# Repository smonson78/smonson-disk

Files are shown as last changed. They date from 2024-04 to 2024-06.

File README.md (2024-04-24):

# Smonson Disk
SD card (2x) to ACSI hard drive interface.

This project aims to develop a reliable and useful hard drive solution for Atari ST with two SD card sockets and a
battery-backed clock, satisfying the ACSI protocol, voltage, and timing requirements as given in available specifications.

Features:
- FPGA-controlled ACSI interface to ensure timing conforms to the specification
- One front-mounted removable SD card socket
- One internally-mounted microSD card socket
- SD cards running on a 10MHz SPI bus (1.25MB/s throughput)
- Battery-backed real-time clock
- GUI configuration from ST (once someone writes it...) and stored in EEPROM
- Open-source, so if you want a feature all you have to do is write it and fit it into the 110KB of code space that is currently left!

## How to build and upload:

### Building the microcontroller firmware:
#### Prerequisites
You will need to install:
- A version of GCC that includes support for `avr128da` microcontrollers, cross-compiled for AVR (e.g. 5.4.0).
- A very recent version of avr-libc that has support for `avr128da` microcontrollers - https://www.nongnu.org/avr-libc/. You may need to get this from their github repo.
- A copy of the avr128da "atpack" from Microchip - go to https://packs.download.microchip.com/ and search for `avr128da`; "
Microchip AVR-Dx Series Device Support (2.4.286)" will pop open. Download this file, then change the file extension to `.zip` 
and unzip it into the directory `mcu-source/atpack`.
- (if you are using an Arduino as a programmer) A copy of jtag2updi from the githup repo here: https://github.com/ElTangas/jtag2updi. You will already have this on your system from when you programmed the device.

#### Building
1. Inside `mcu-source`:
1. Update the `Makefile` and set up `LIBC` variable to reflect the path to `avr-libc` on your system
1. Update the `AVRDUDE` variable to reflect your programmer setup (probably just the `avrdude.conf` path)
1. With the UPDI programmer connected, build the source and flash the microcontroller with `make flash`

### Building the FPGA configuration ROM image:

#### Prerequisites
You will need to install Quartus Lite which is a free download from Intel, although you will need to create an account.
Make sure you install MAX V family support
You will also need a "USB-Blaster" or compatible programmer.
If using Linux, you will very likely need to install a `udev` "rules" file for the programmer before it'll work.

#### Building
Just open the project in Quartus, go to "start compilation", then after it's compiled, open the programmer tool and program the chip. It should auto-detect the settings. If it doesn't find the USB Blaster hardware then it's probably udev's fault.

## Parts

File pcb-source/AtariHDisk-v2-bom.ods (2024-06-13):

Designator | Footprint | Quantity | Designation | Supplier and ref
C5,C8,C9 | C_1206_3216Metric | 3 | 4.7uF | 187-CL31B475KPHNNNE
C3 | CP_Radial_D5.0mm_P2.00mm | 1 | 4.7uF | 232-16ZLH100MEFC5X11
J1 | PinHeader_2x05_P2.54mm_Vertical | 1 | JTAG
R12,R11,R25,R26 | R_0805_2012Metric | 4 | 1K
R13,R3 | R_0805_2012Metric | 2 | 10K
C18,C12,C17,C16,C14,C15,C21,C19,C25,C20,C26,C24,C27,C4,C11,C28,C13 | C_0603_1608Metric | 17 | 0.1uF
H4,H3,H1,H2 | Altronics_H0190_mounting_hole | 4 | MountingHole
U7 | SOT-223-3_TabPin2 | 1 | AMS1117-3.3 | 621-AZ1117CH-3.3TRG1
U8 | SOT-223-3_TabPin2 | 1 | AMS1117-1.8 | 621-AZ1117CH-1.8TRG1
U4 | XO_7x5 | 1 | Oscillator7x5 | 729-FNETHE025
J5 | BarrelJack_Horizontal | 1 | Conn_01x02_Female | 710-694106301002
U9 | TQFP-100_14x14mm_P0.5mm | 1 | 5M80Z | 5M80ZT100C5N
U5 | MSOP-10_3x3mm_P0.5mm | 1 | MCP795xx | 579-MCP79510-I/MS
U3 | SOT-223-3_TabPin2 | 1 | AZ1117-5.0 | 621-AZ1117CH-5.0TRG1
D6,D5 | LED_D3.0mm_Horizontal_O1.27mm_Z2.0mm | 2 | LED | 78-TLUG2401 78-TLUO2401
C22,C10,C2,C7 | C_0603_1608Metric | 4 | C | 963-UMK107BJ104KA-T
J2 | PinHeader_1x02_P2.54mm_Vertical | 1 | Program_enable | 737-PH2-80-UA
R19,R20,R24,R23,R15,R2,R21,R14,R18,R17,R1,R22 | R_0805_2012Metric | 12 | 220 | 603-RC0805JR-13220RL
Q4,Q3 | SOT-23 | 2 | BC847 | 637-BC847A
U2 | TSSOP-16_4.4x5mm_P0.65mm | 1 | MAX3232 | 595-MAX3232IPWR
U6 | LQFP-48_7x7mm_P0.5mm | 1 | STM32C031CxT | 511-STM32C031C6T6
Y1 | Crystal_SMD_ECX_31B-2Pin_3.2x1.5mm | 1 | 32KHz | ECS-.327-6-34R-C-TR
J14 | MicroSD_card_MSD-4-A | 1 | MicroSD Card 0 | 179-MSD-4-A
D2,D1 | D_1206_3216Metric | 2 | D_Schottky | 581-SD1206S040S1R0
J3 | Amphenol_SD_Card_GSD090012SEU | 1 | SD Card 1 | 523-GSD090012SEU
U1 | TSSOP-20_4.4x6.5mm_P0.65mm | 1 | 74LVC245 | 595-SN74LVC245APWR
J6 | PinHeader_2x03_P2.54mm_Vertical | 1 | Conn_02x03_Odd_Even | 737-PH2-80-UA
C29,C30 | C_0603_1608Metric | 2 | 4pF | 603-CC0603BRNPO9BN4R
D3 | D_SMA | 1 | D | 241-GS1MWG_R1_00001
J7 | PinHeader_2x05_P2.54mm_Vertical | 1 | ST-LINK
U11 | TSSOP-24_4.4x7.8mm_P0.65mm | 1 | 74LVC8T245 | 771-74LVC8T245PW118
JP1 | SolderJumper-2_P1.3mm_Open_RoundedPad1.0x1.5mm | 1 | SolderJumper_2_Open
J10 | IDC-Header_DB19_P2.54mm_Horizontal | 1 | ST ACSI BUS | 737-BHR-20-HUA
BT1 | 712-BAT-HLD-002-SMT | 1 | Battery_Cell | 712-BAT-HLD-002-SMT

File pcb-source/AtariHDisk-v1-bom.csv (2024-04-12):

Id | Designator | Footprint | Quantity | Designation | Supplier and ref
1 | C5,C8,C9 | C_1206_3216Metric | 3 | 4.7uF
2 | J4 | PinHeader_2x03_P2.54mm_Vertical | 1 | UPDI
3 | C3 | CP_Radial_D5.0mm_P2.00mm | 1 | 4.7uF
4 | J1 | PinHeader_2x05_P2.54mm_Vertical | 1 | JTAG
5 | R12,R11 | R_0805_2012Metric | 2 | 1K
6 | R13,R3 | R_0805_2012Metric | 2 | 10K
7 | C18,C12,C17,C16,C14,C15,C19,C25,C6,C20,C26,C24,C27,C4,C11,C13,C1 | C_0603_1608Metric | 17 | 0.1uF
8 | H4,H3,H1,H2 | Altronics_H0190_mounting_hole | 4 | MountingHole
9 | U7 | SOT-223-3_TabPin2 | 1 | AMS1117-3.3
10 | U8 | SOT-223-3_TabPin2 | 1 | AMS1117-1.8
11 | U4 | XO_7x5 | 1 | Oscillator7x5
12 | J5 | BarrelJack_Horizontal | 1 | Conn_01x02_Female
13 | C21,C22,C10,C28,C2,C7 | C_0603_1608Metric | 6 | C
14 | U9 | TQFP-100_14x14mm_P0.5mm | 1 | 5M80Z
15 | U5 | MSOP-10_3x3mm_P0.5mm | 1 | MCP795xx
16 | U3 | SOT-223-3_TabPin2 | 1 | AZ1117-5.0
17 | D6,D5 | LED_D3.0mm_Horizontal_O1.27mm_Z2.0mm | 2 | LED
18 | J2 | PinHeader_1x02_P2.54mm_Vertical | 1 | Program_enable
19 | U6 | LQFP-48_7x7mm_P0.5mm | 1 | ~
20 | R19,R20,R24,R23,R15,R2,R21,R14,R1,R22 | R_0805_2012Metric | 10 | 220
21 | Q4,Q3 | SOT-23 | 2 | BC847
22 | U2 | TSSOP-16_4.4x5mm_P0.65mm | 1 | MAX3232
23 | Y1 | Crystal_C38-LF_D3.0mm_L8.0mm_Vertical | 1 | 32KHz
24 | J14 | MicroSD_card_MSD-4-A | 1 | MicroSD Card 0
25 | D2,D1 | D_1206_3216Metric | 2 | D_Schottky
26 | R25,R26 | R_0805_2012Metric | 2 | R
27 | J3 | Amphenol_SD_Card_GSD090012SEU | 1 | SD Card 1
28 | U1 | TSSOP-20_4.4x6.5mm_P0.65mm | 1 | 74LVC245
29 | R18,R17 | R_0805_2012Metric | 2 | 2K
30 | J6 | PinHeader_2x03_P2.54mm_Vertical | 1 | Conn_02x03_Odd_Even
31 | C29,C30 | C_0603_1608Metric | 2 | 3pF
32 | D3 | D_1206_3216Metric | 1 | D
33 | U11 | TSSOP-24_4.4x7.8mm_P0.65mm | 1 | 74LVC8T245
34 | J10 | IDC-Header_DB19_P2.54mm_Horizontal | 1 | ST ACSI BUS
35 | BT1 | 712-BAT-HLD-002-SMT | 1 | Battery_Cell

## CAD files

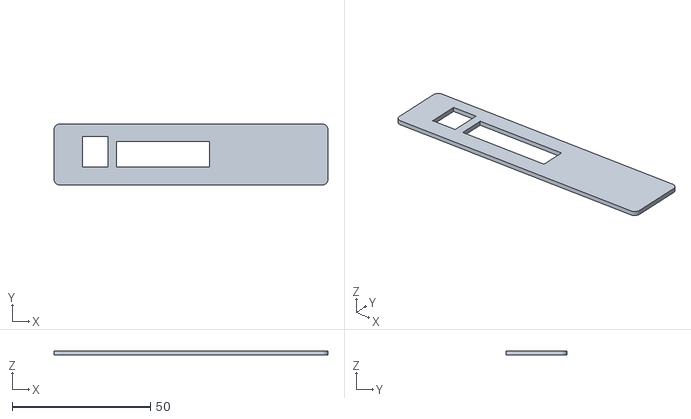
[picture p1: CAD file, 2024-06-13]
enclosure/back.stl
99.0 x 22.0 x 1.50

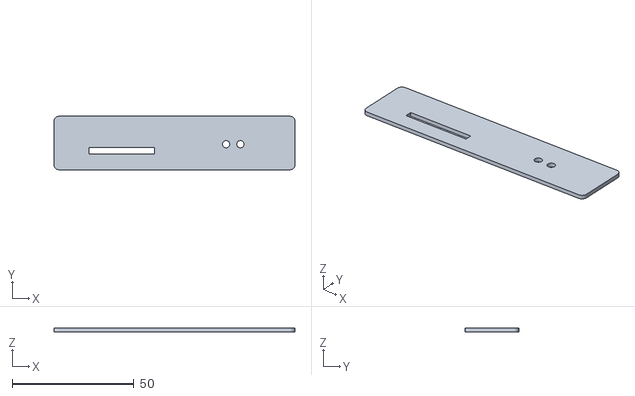
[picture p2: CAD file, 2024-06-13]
enclosure/front.stl
99.0 x 22.0 x 1.50

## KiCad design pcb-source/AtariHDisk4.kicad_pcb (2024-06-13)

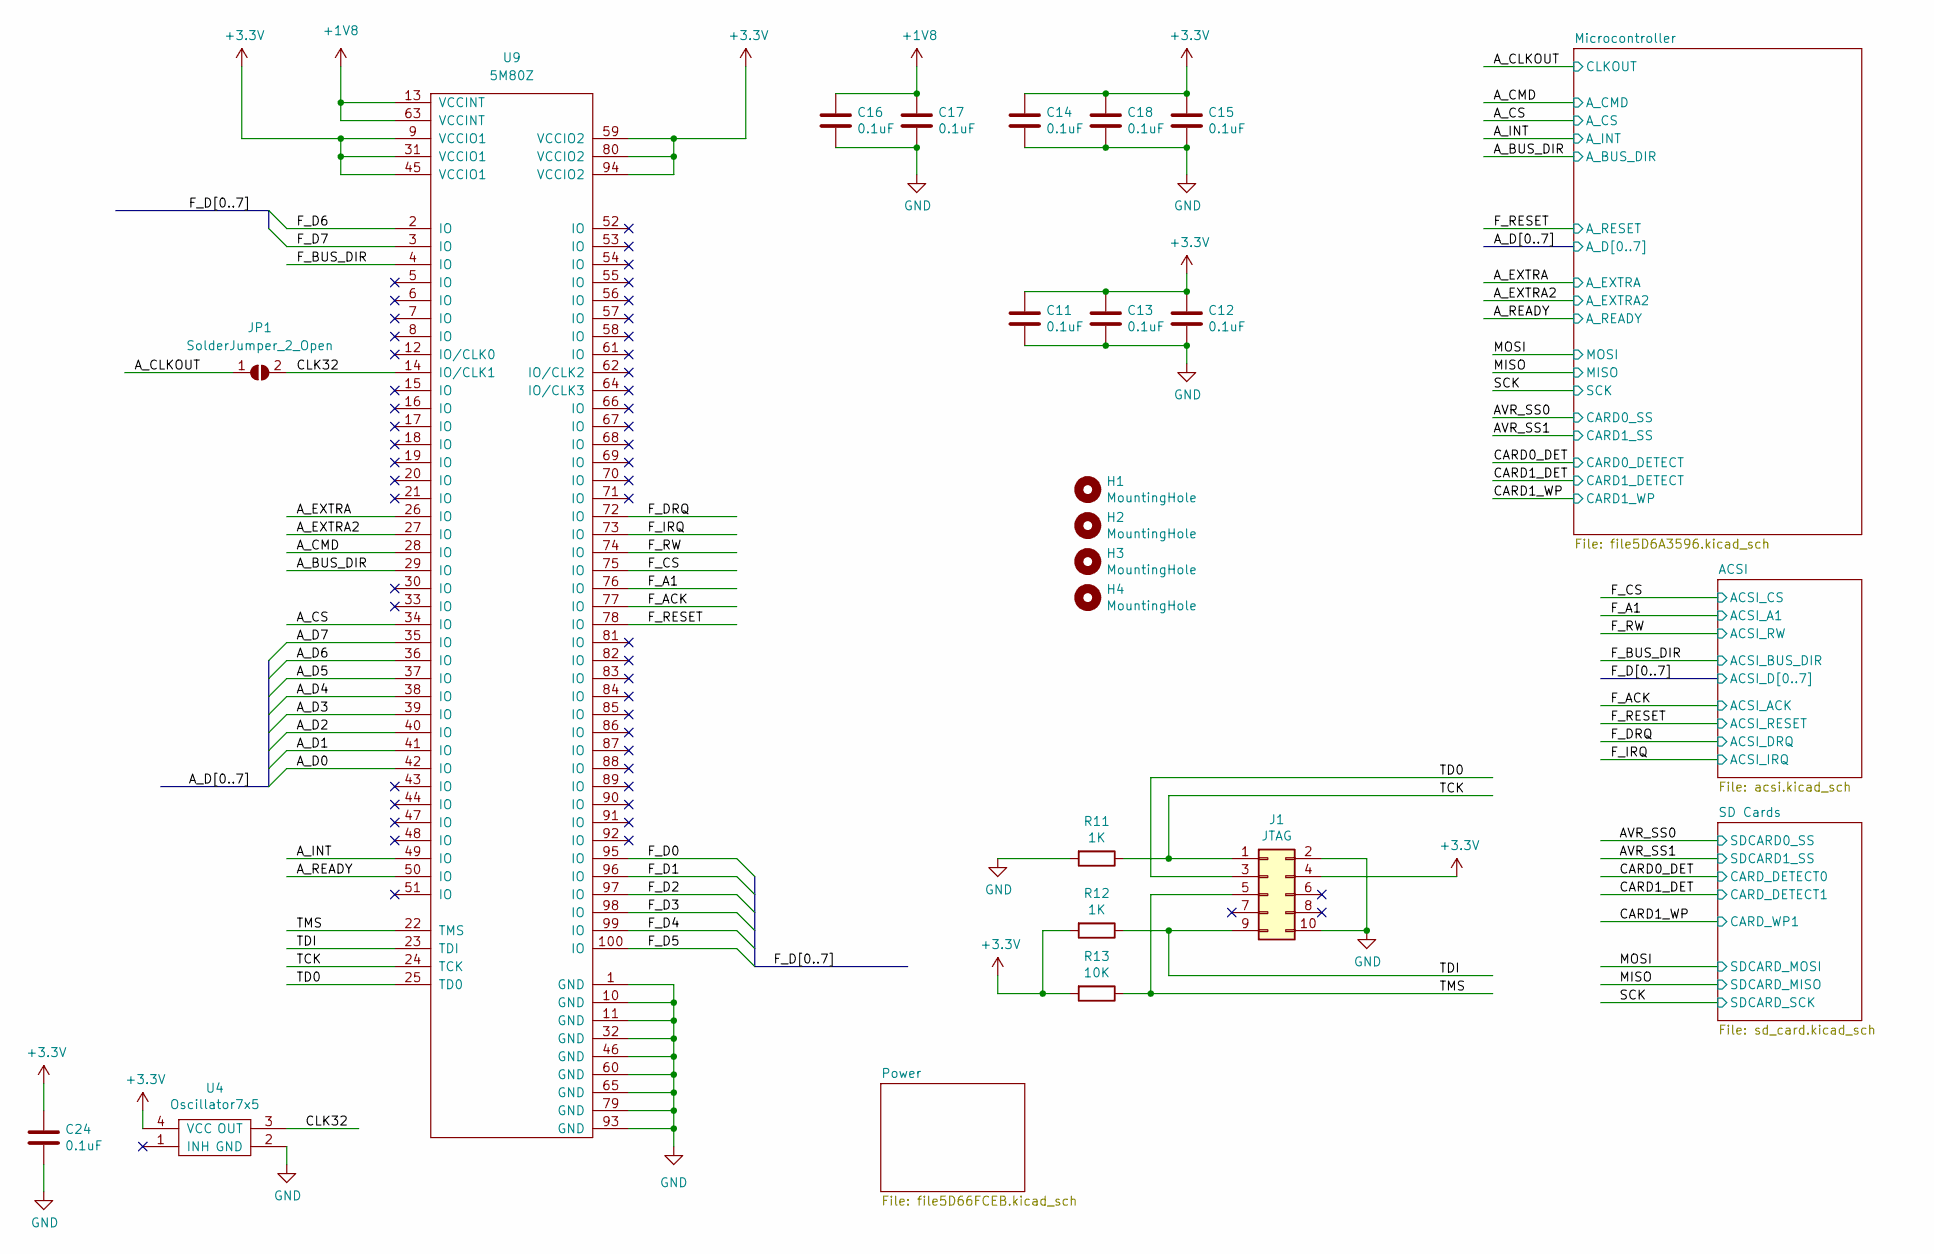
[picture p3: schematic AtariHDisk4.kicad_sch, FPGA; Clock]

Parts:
C11, C12, C13, C14, C15, C16, C17, C18, C24: 0.1uF; C_0603_1608Metric
H1, H2, H3, H4: MountingHole; Altronics_H0190_mounting_hole
J1: JTAG; PinHeader_2x05_P2.54mm_Vertical
JP1: SolderJumper_2_Open; SolderJumper-2_P1.3mm_Open_RoundedPad1.0x1.5mm
R11, R12: 1K; R_0805_2012Metric
R13: 10K; R_0805_2012Metric
U4: Oscillator7x5; XO_7x5
U9: 5M80Z; TQFP-100_14x14mm_P0.5mm

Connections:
+1V8: C16.1, C17.1, U9.13 (VCCINT), U9.63 (VCCINT); also elsewhere on the board
+3V3: C11.1, C12.1, C13.1, C14.1, C15.1, C18.1, C24.1, J1.4, R12.2, R13.2, U4.4 (VCC), U9.9 (VCCIO1), U9.31 (VCCIO1), U9.45 (VCCIO1), U9.59 (VCCIO2), U9.80 (VCCIO2), U9.94 (VCCIO2); also elsewhere on the board
/A_BUS_DIR: U9.29 (IO); also elsewhere on the board
/A_CLKOUT: JP1.1 (A); also elsewhere on the board
/A_CMD: U9.28 (IO); also elsewhere on the board
/A_CS: U9.34 (IO); also elsewhere on the board
/A_D0: U9.42 (IO); also elsewhere on the board
/A_D1: U9.41 (IO); also elsewhere on the board
/A_D2: U9.40 (IO); also elsewhere on the board
/A_D3: U9.39 (IO); also elsewhere on the board
/A_D4: U9.38 (IO); also elsewhere on the board
/A_D5: U9.37 (IO); also elsewhere on the board
/A_D6: U9.36 (IO); also elsewhere on the board
/A_D7: U9.35 (IO); also elsewhere on the board
/A_EXTRA: U9.26 (IO); also elsewhere on the board
/A_EXTRA2: U9.27 (IO); also elsewhere on the board
/A_INT: U9.49 (IO); also elsewhere on the board
/A_READY: U9.50 (IO); also elsewhere on the board
/CLK32: JP1.2 (B), U4.3 (OUT), U9.14 (IO/CLK1)
/F_A1: U9.76 (IO); also elsewhere on the board
/F_ACK: U9.77 (IO); also elsewhere on the board
/F_BUS_DIR: U9.4 (IO); also elsewhere on the board
/F_CS: U9.75 (IO); also elsewhere on the board
/F_D0: U9.95 (IO); also elsewhere on the board
/F_D1: U9.96 (IO); also elsewhere on the board
/F_D2: U9.97 (IO); also elsewhere on the board
/F_D3: U9.98 (IO); also elsewhere on the board
/F_D4: U9.99 (IO); also elsewhere on the board
/F_D5: U9.100 (IO); also elsewhere on the board
/F_D6: U9.2 (IO); also elsewhere on the board
/F_D7: U9.3 (IO); also elsewhere on the board
/F_DRQ: U9.72 (IO); also elsewhere on the board
/F_IRQ: U9.73 (IO); also elsewhere on the board
/F_RESET: U9.78 (IO); also elsewhere on the board
/F_RW: U9.74 (IO); also elsewhere on the board
/TCK: J1.1, R11.1, U9.24 (TCK)
/TD0: J1.3, U9.25 (TD0)
/TDI: J1.9, R12.1, U9.23 (TDI)
/TMS: J1.5, R13.1, U9.22 (TMS)
GND: C11.2, C12.2, C13.2, C14.2, C15.2, C16.2, C17.2, C18.2, C24.2, J1.2, J1.10, R11.2, U4.2 (GND), U9.1 (GND), U9.10 (GND), U9.11 (GND), U9.32 (GND), U9.46 (GND), U9.60 (GND), U9.65 (GND), U9.79 (GND), U9.93 (GND); also elsewhere on the board

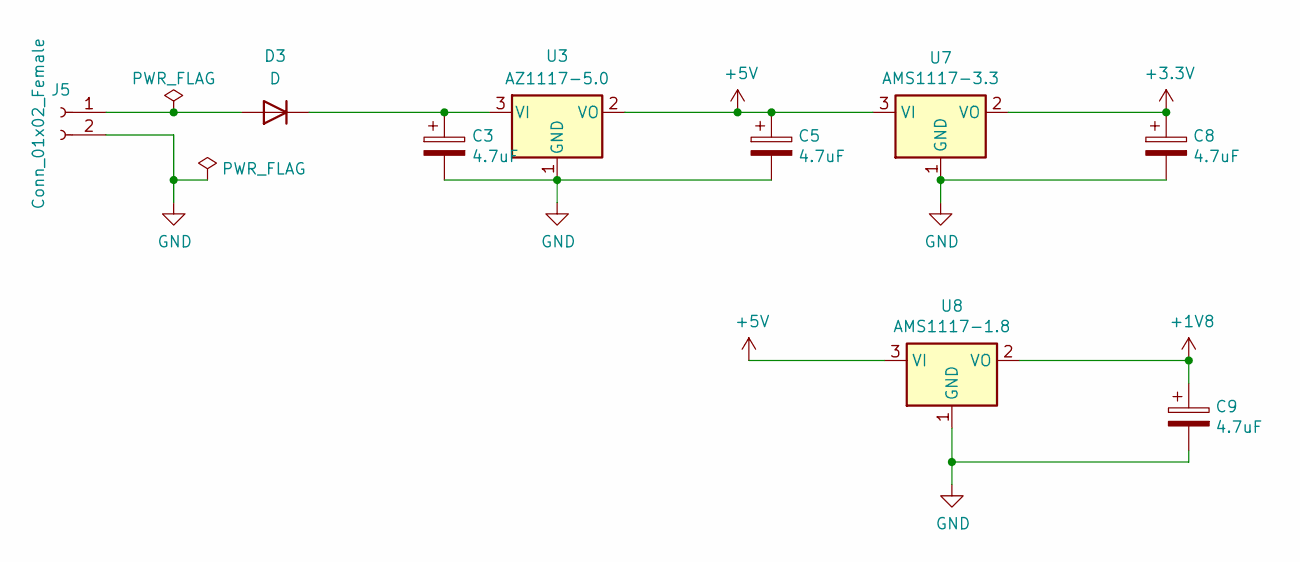
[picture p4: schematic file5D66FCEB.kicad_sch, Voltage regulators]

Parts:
C3: 4.7uF; CP_Radial_D5.0mm_P2.00mm
C5, C8, C9: 4.7uF; C_1206_3216Metric
D3: D; D_SMA
J5: Conn_01x02_Female; BarrelJack_Horizontal
U3: AZ1117-5.0; SOT-223-3_TabPin2
U7: AMS1117-3.3; SOT-223-3_TabPin2
U8: AMS1117-1.8; SOT-223-3_TabPin2

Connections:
+1V8: C9.1, U8.2 (VO); also elsewhere on the board
+3V3: C8.1, U7.2 (VO); also elsewhere on the board
+5V: C5.1, U3.2 (VO), U7.3 (VI), U8.3 (VI); also elsewhere on the board
GND: C3.2, C5.2, C8.2, C9.2, J5.2, U3.1 (GND), U7.1 (GND), U8.1 (GND); also elsewhere on the board
unnamed: D3.2 (A), J5.1
unnamed: C3.1, D3.1 (K), U3.3 (VI)

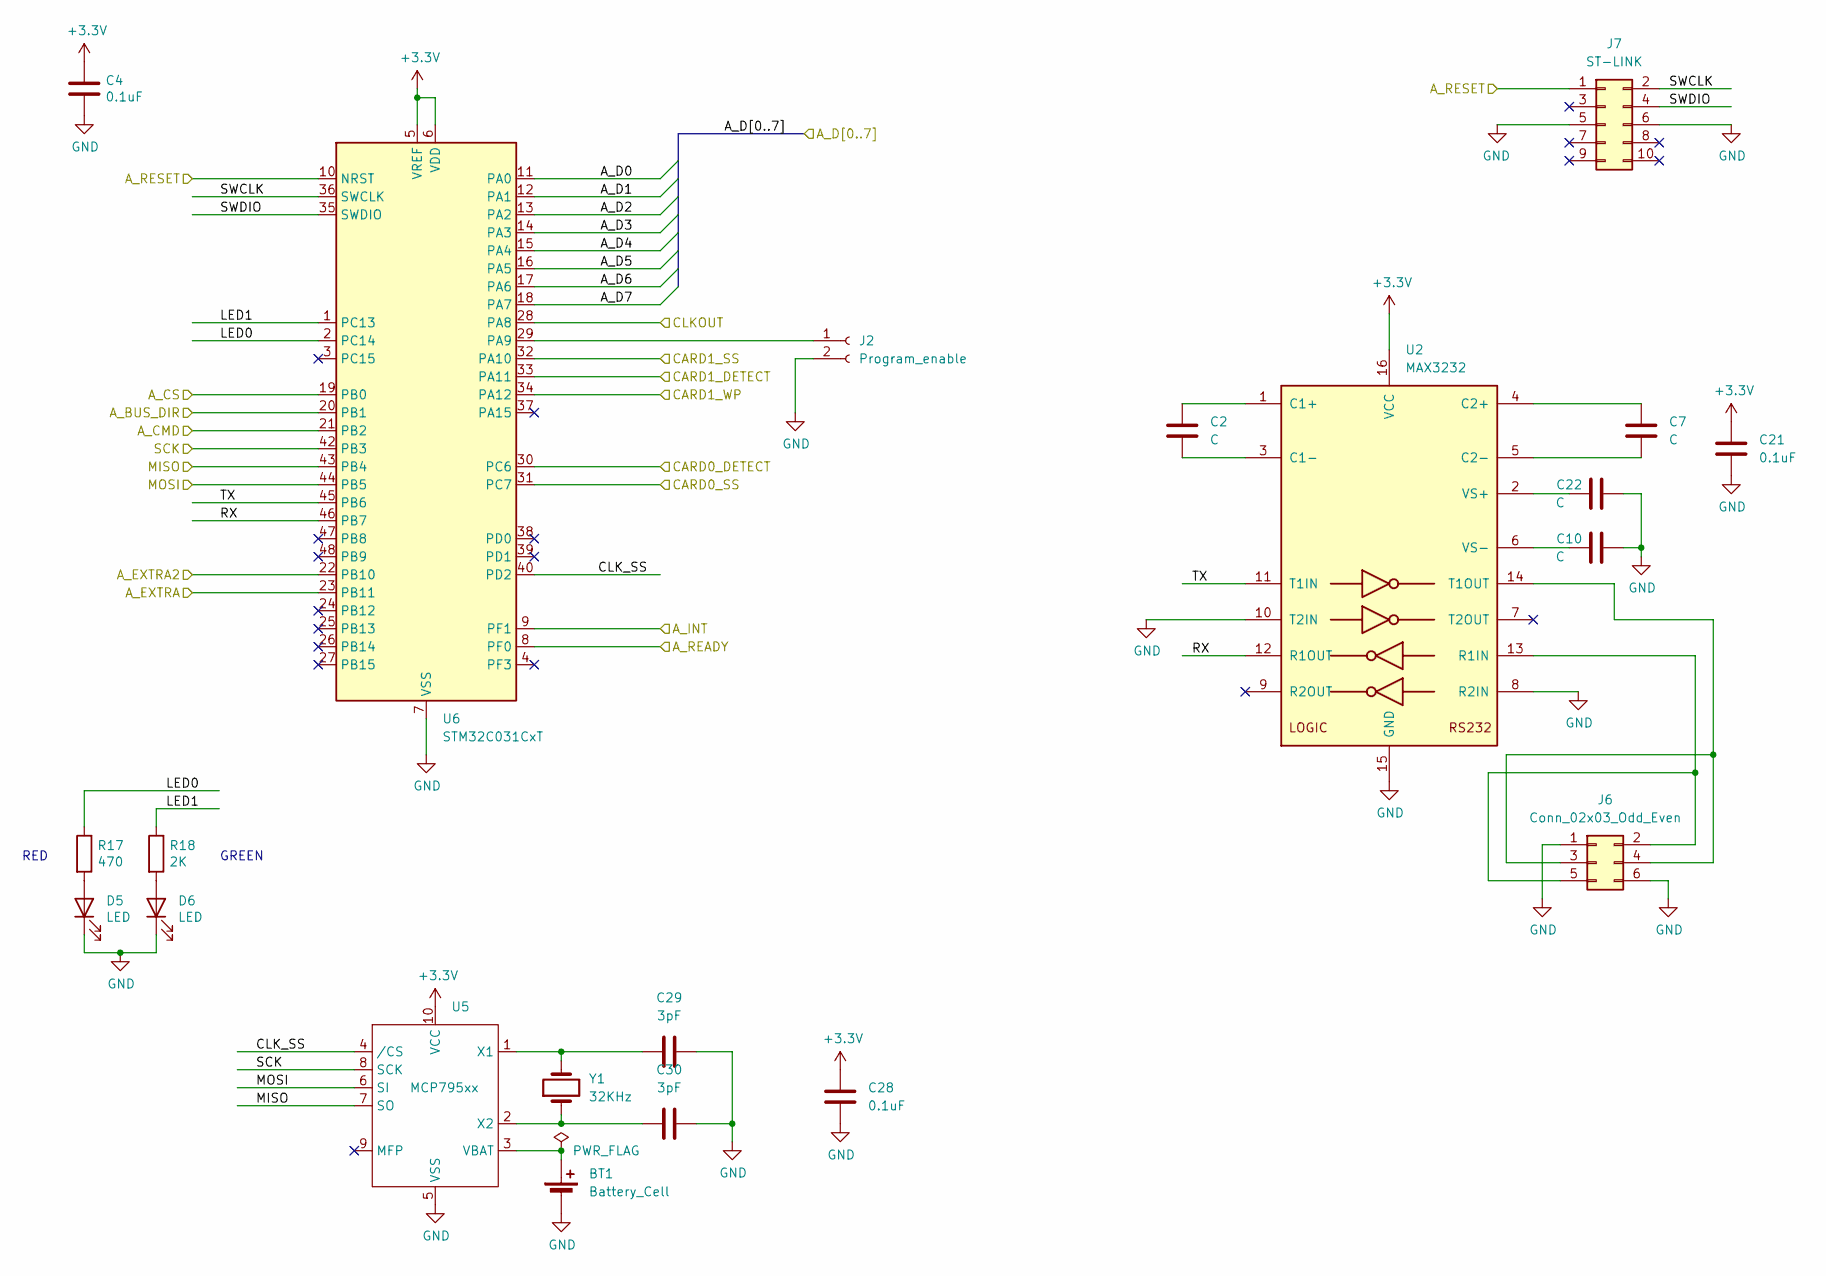
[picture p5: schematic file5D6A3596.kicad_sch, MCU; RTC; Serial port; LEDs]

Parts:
BT1: Battery_Cell; 712-BAT-HLD-002-SMT
C2, C7, C10, C22: C; C_0603_1608Metric
C4, C21, C28: 0.1uF; C_0603_1608Metric
C29, C30: 3pF; C_0603_1608Metric
D5, D6: LED; LED_D3.0mm_Horizontal_O1.27mm_Z2.0mm
J2: Program_enable; PinHeader_1x02_P2.54mm_Vertical
J6: Conn_02x03_Odd_Even; PinHeader_2x03_P2.54mm_Vertical
J7: ST-LINK; PinHeader_2x05_P2.54mm_Vertical
R17: 470; R_0805_2012Metric
R18: 2K; R_0805_2012Metric
U2: MAX3232; TSSOP-16_4.4x5mm_P0.65mm
U5: MCP795xx; MSOP-10_3x3mm_P0.5mm
U6: STM32C031CxT; LQFP-48_7x7mm_P0.5mm
Y1: 32KHz; Crystal_SMD_ECX_31B-2Pin_3.2x1.5mm

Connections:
+3V3: C4.1, C21.1, C28.1, U2.16 (VCC), U5.10 (VCC), U6.5 (VREF), U6.6 (VDD); also elsewhere on the board
/AVR_SS0: U6.31 (PC7); also elsewhere on the board
/AVR_SS1: U6.32 (PA10); also elsewhere on the board
/A_BUS_DIR: U6.20 (PB1); also elsewhere on the board
/A_CLKOUT: U6.28 (PA8); also elsewhere on the board
/A_CMD: U6.21 (PB2); also elsewhere on the board
/A_CS: U6.19 (PB0); also elsewhere on the board
/A_D0: U6.11 (PA0); also elsewhere on the board
/A_D1: U6.12 (PA1); also elsewhere on the board
/A_D2: U6.13 (PA2); also elsewhere on the board
/A_D3: U6.14 (PA3); also elsewhere on the board
/A_D4: U6.15 (PA4); also elsewhere on the board
/A_D5: U6.16 (PA5); also elsewhere on the board
/A_D6: U6.17 (PA6); also elsewhere on the board
/A_D7: U6.18 (PA7); also elsewhere on the board
/A_EXTRA: U6.23 (PB11); also elsewhere on the board
/A_EXTRA2: U6.22 (PB10); also elsewhere on the board
/A_INT: U6.9 (PF1); also elsewhere on the board
/A_READY: U6.8 (PF0); also elsewhere on the board
/CARD0_DET: U6.30 (PC6); also elsewhere on the board
/CARD1_DET: U6.33 (PA11); also elsewhere on the board
/CARD1_WP: U6.34 (PA12); also elsewhere on the board
/F_RESET: J7.1, U6.10 (NRST); also elsewhere on the board
/MISO: U5.7 (SO), U6.43 (PB4); also elsewhere on the board
/MOSI: U5.6 (SI), U6.44 (PB5); also elsewhere on the board
/Microcontroller/CLK_SS: U5.4 (/CS), U6.40 (PD2)
/Microcontroller/LED0: R17.1, U6.2 (PC14)
/Microcontroller/LED1: R18.1, U6.1 (PC13)
/Microcontroller/RX: U2.12 (R1OUT), U6.46 (PB7)
/Microcontroller/SWCLK: J7.2, U6.36 (SWCLK)
/Microcontroller/SWDIO: J7.4, U6.35 (SWDIO)
/Microcontroller/TX: U2.11 (T1IN), U6.45 (PB6)
/SCK: U5.8 (SCK), U6.42 (PB3); also elsewhere on the board
GND: BT1.2 (-), C4.2, C10.2, C21.2, C22.2, C28.2, C29.2, C30.2, D5.1 (K), D6.1 (K), J2.2, J6.1, J6.6, J7.5, J7.6, U2.8 (R2IN), U2.10 (T2IN), U2.15 (GND), U5.5 (VSS), U6.7 (VSS); also elsewhere on the board
unnamed: BT1.1 (+), U5.3 (VBAT)
unnamed: D5.2 (A), R17.2
unnamed: D6.2 (A), R18.2
unnamed: J2.1, U6.29 (PA9)
unnamed: J6.2, J6.5, U2.13 (R1IN)
unnamed: J6.3, J6.4, U2.14 (T1OUT)
unnamed: C2.1, U2.1 (C1+)
unnamed: C2.2, U2.3 (C1-)
unnamed: C7.1, U2.4 (C2+)
unnamed: C7.2, U2.5 (C2-)
unnamed: C22.1, U2.2 (VS+)
unnamed: C10.1, U2.6 (VS-)
unnamed: C29.1, U5.1 (X1), Y1.2
unnamed: C30.1, U5.2 (X2), Y1.1

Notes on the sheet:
GREEN
RED

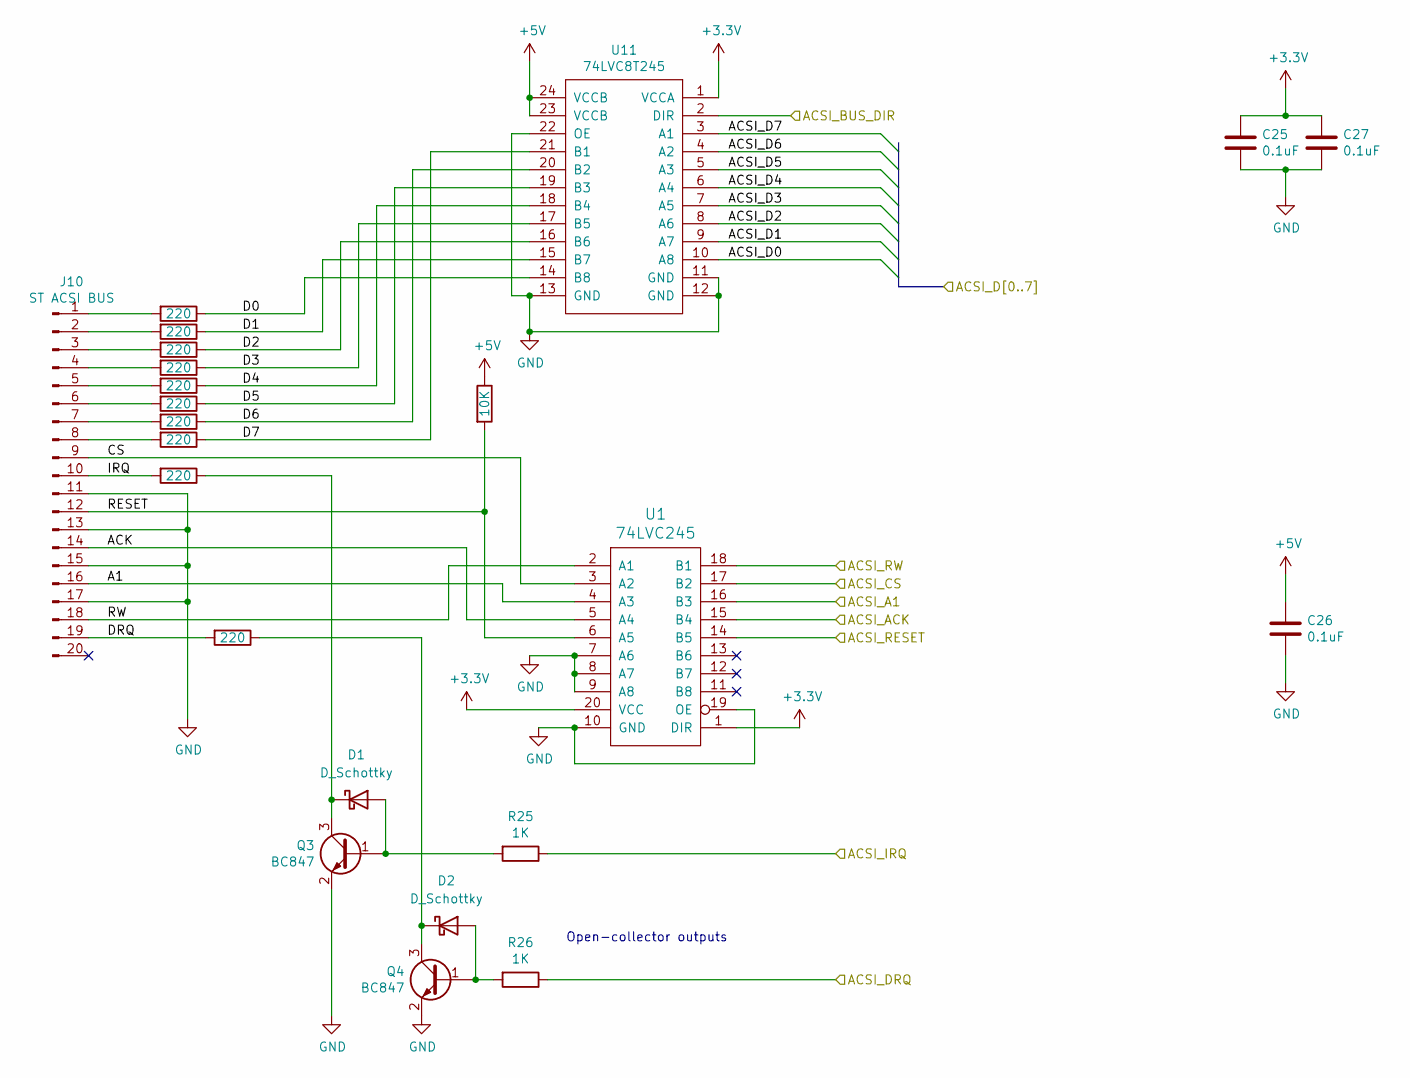
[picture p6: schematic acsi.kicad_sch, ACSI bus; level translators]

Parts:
C25, C26, C27: 0.1uF; C_0603_1608Metric
D1, D2: D_Schottky; D_1206_3216Metric
J10: ST ACSI BUS; IDC-Header_DB19_P2.54mm_Horizontal
Q3, Q4: BC847; SOT-23
R1, R2, R14, R15, R19, R20, R21, R22, R23, R24: 220; R_0805_2012Metric
R3: 10K; R_0805_2012Metric
R25, R26: 1K; R_0805_2012Metric
U1: 74LVC245; TSSOP-20_4.4x6.5mm_P0.65mm
U11: 74LVC8T245; TSSOP-24_4.4x7.8mm_P0.65mm

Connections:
+3V3: C25.1, C27.1, U1.1 (DIR), U1.20 (VCC), U11.1 (VCCA); also elsewhere on the board
+5V: C26.1, R3.1, U11.23 (VCCB), U11.24 (VCCB); also elsewhere on the board
/ACSI/A1: J10.16, U1.4 (A3)
/ACSI/ACK: J10.14, U1.5 (A4)
/ACSI/CS: J10.9, U1.3 (A2)
/ACSI/D0: R14.1, U11.14 (B8)
/ACSI/D1: R15.1, U11.15 (B7)
/ACSI/D2: R19.1, U11.16 (B6)
/ACSI/D3: R20.1, U11.17 (B5)
/ACSI/D4: R21.1, U11.18 (B4)
/ACSI/D5: R22.1, U11.19 (B3)
/ACSI/D6: R23.1, U11.20 (B2)
/ACSI/D7: R24.1, U11.21 (B1)
/ACSI/DRQ: J10.19, R2.2
/ACSI/IRQ: J10.10, R1.2
/ACSI/RESET: J10.12, R3.2, U1.6 (A5)
/ACSI/RW: J10.18, U1.2 (A1)
/F_A1: U1.16 (B3); also elsewhere on the board
/F_ACK: U1.15 (B4); also elsewhere on the board
/F_BUS_DIR: U11.2 (DIR); also elsewhere on the board
/F_CS: U1.17 (B2); also elsewhere on the board
/F_D0: U11.10 (A8); also elsewhere on the board
/F_D1: U11.9 (A7); also elsewhere on the board
/F_D2: U11.8 (A6); also elsewhere on the board
/F_D3: U11.7 (A5); also elsewhere on the board
/F_D4: U11.6 (A4); also elsewhere on the board
/F_D5: U11.5 (A3); also elsewhere on the board
/F_D6: U11.4 (A2); also elsewhere on the board
/F_D7: U11.3 (A1); also elsewhere on the board
/F_DRQ: R26.1; also elsewhere on the board
/F_IRQ: R25.1; also elsewhere on the board
/F_RESET: U1.14 (B5); also elsewhere on the board
/F_RW: U1.18 (B1); also elsewhere on the board
GND: C25.2, C26.2, C27.2, J10.11, J10.13, J10.15, J10.17, Q3.2 (E), Q4.2 (E), U1.7 (A6), U1.8 (A7), U1.9 (A8), U1.10 (GND), U1.19 (OE), U11.11 (GND), U11.12 (GND), U11.13 (GND), U11.22 (OE); also elsewhere on the board
unnamed: D1.2 (A), Q3.1 (B), R25.2
unnamed: D1.1 (K), Q3.3 (C), R1.1
unnamed: D2.2 (A), Q4.1 (B), R26.2
unnamed: D2.1 (K), Q4.3 (C), R2.1
unnamed: J10.1, R14.2
unnamed: J10.2, R15.2
unnamed: J10.3, R19.2
unnamed: J10.4, R20.2
unnamed: J10.5, R21.2
unnamed: J10.6, R22.2
unnamed: J10.7, R23.2
unnamed: J10.8, R24.2

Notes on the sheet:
Open-collector outputs

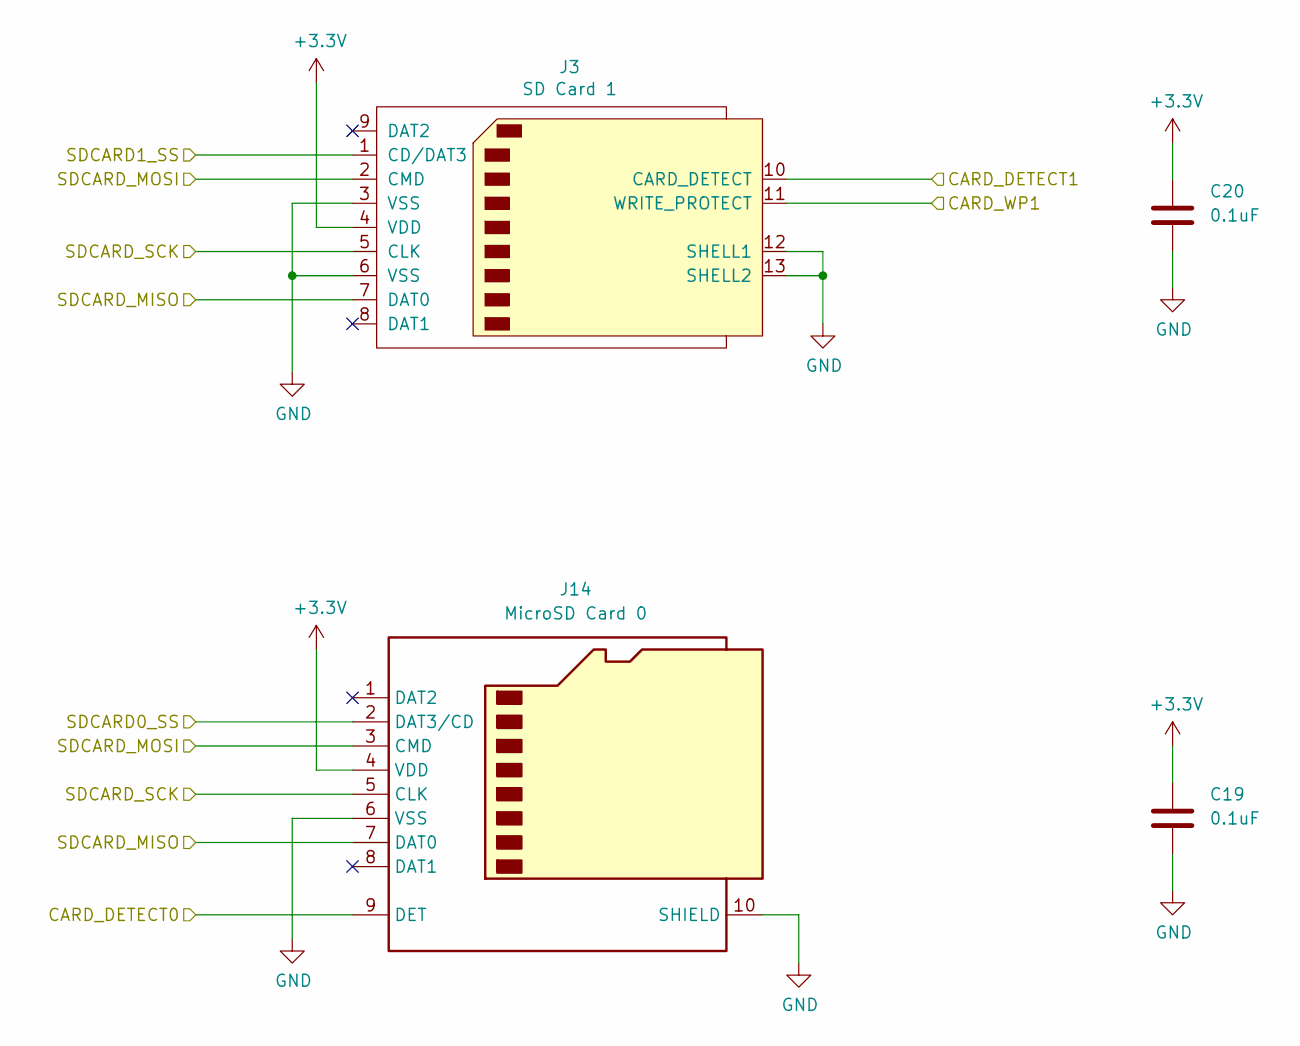
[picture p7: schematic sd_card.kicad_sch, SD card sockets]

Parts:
C19, C20: 0.1uF; C_0603_1608Metric
J3: SD Card 1; Amphenol_SD_Card_GSD090012SEU
J14: MicroSD Card 0; MicroSD_card_MSD-4-A

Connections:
+3V3: C19.1, C20.1, J3.4 (VDD), J14.4 (VDD); also elsewhere on the board
/AVR_SS0: J14.2 (DAT3/CD); also elsewhere on the board
/AVR_SS1: J3.1 (CD/DAT3); also elsewhere on the board
/CARD0_DET: J14.9 (DET); also elsewhere on the board
/CARD1_DET: J3.10 (CARD_DETECT); also elsewhere on the board
/CARD1_WP: J3.11 (WRITE_PROTECT); also elsewhere on the board
/MISO: J3.7 (DAT0), J14.7 (DAT0); also elsewhere on the board
/MOSI: J3.2 (CMD), J14.3 (CMD); also elsewhere on the board
/SCK: J3.5 (CLK), J14.5 (CLK); also elsewhere on the board
GND: C19.2, C20.2, J3.3 (VSS), J3.6 (VSS), J3.12 (SHELL1), J3.13 (SHELL2), J14.6 (VSS), J14.10 (SHIELD); also elsewhere on the board

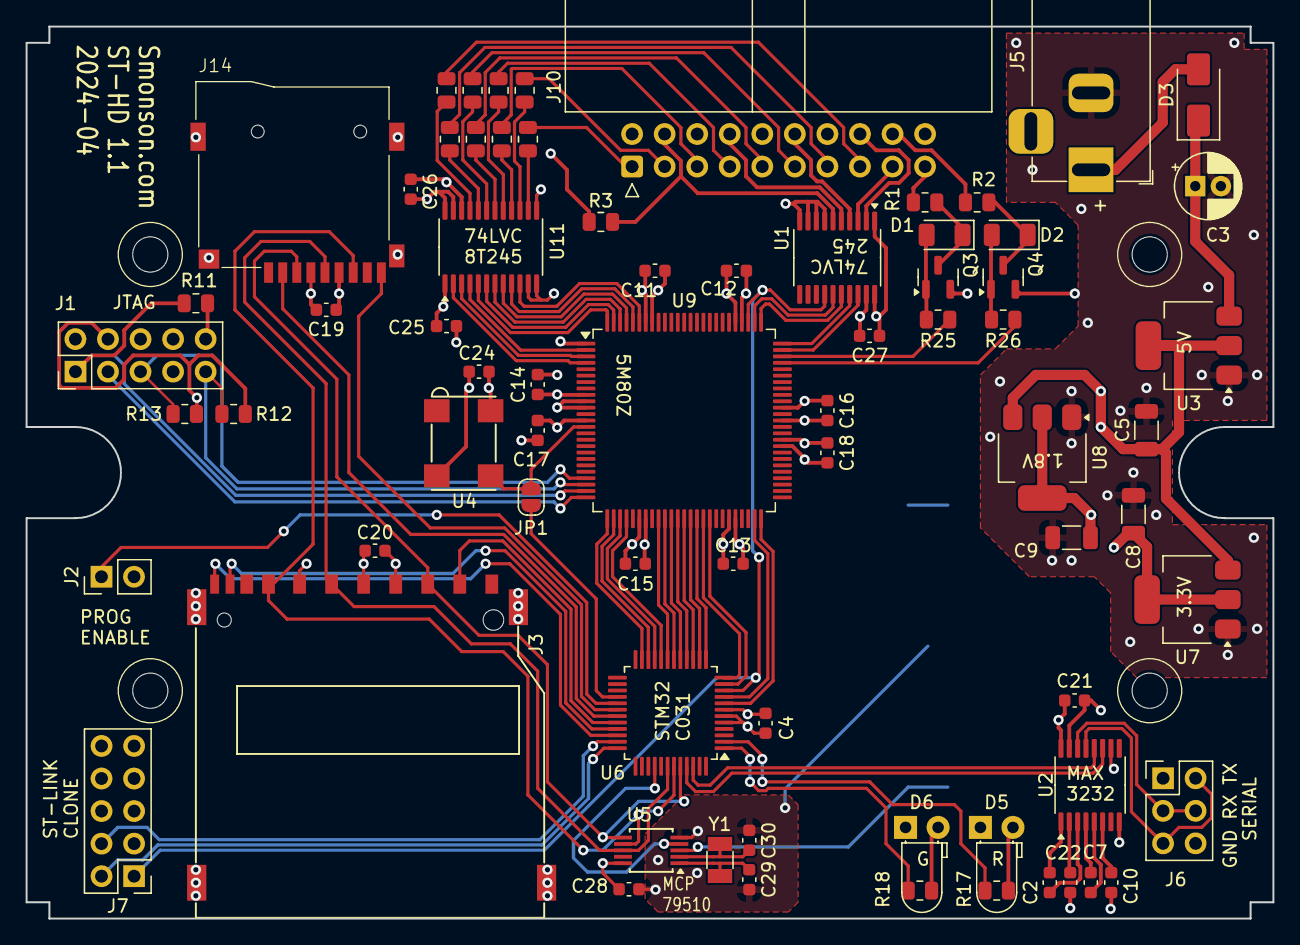
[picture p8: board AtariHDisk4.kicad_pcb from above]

Board: 4 copper layers, 97.3 x 69.6 mm, 77 parts (1 on the bottom side), 99 nets.

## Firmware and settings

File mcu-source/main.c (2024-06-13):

#include "stm32c0xx.h"

#include <stdint.h>

#include "sdcard.h"
#include "commands.h"
#include "acsi.h"
#include "fpga_comm.h"
#include "serial.h"
#include "timer0.h"
#include "debug.h"
#include "spi.h"
#include "rtc.h"

/*
 * "Smonson Disk" - Atari ST ACSI hard drive interface (to two SD cards and a real-time clock)
 * Simon Krix © 2024
 * 
 * License: GPL 3 or later https://www.gnu.org/licenses/gpl-3.0.en.html unless otherwise noted.
 */

// Change the HSISYS prescaler from 2 to 0 to increase the clock from 12MHz to 48MHz
void clk_48MHz() {

    // Pump up the flash memory wait states value to 2 since we will be operating above 24MHz
    FLASH->ACR &= ~FLASH_ACR_LATENCY;
    FLASH->ACR |= 0b001 << FLASH_ACR_LATENCY_Pos;

    while ((FLASH->ACR & FLASH_ACR_LATENCY) != (0b001 << FLASH_ACR_LATENCY_Pos)) {
        // wait for new latency to be applied
    }

    // Change HSISYS prescale value from default value 0b010 to 0b000 to get 48MHz operation
    RCC->CR &= ~RCC_CR_HSIDIV_Msk;
    //RCC->CR |= 0b001 << RCC_CR_HSIDIV_Pos; // Prescaler x2
    //RCC->CR |= 0b010 << RCC_CR_HSIDIV_Pos; // Prescaler x4
}

void set_acsi_id_mask() {
    uint8_t acsi_id_mask = 0;
    if (logical_drive[0].sdcard->usable) {
        acsi_id_mask |= (1 << logical_drive[0].acsi_id);
    }
    if (logical_drive[1].sdcard->usable) {
        acsi_id_mask |= (1 << logical_drive[1].acsi_id);
    }
    debug_nocr("Setting ACSI mask to ");
    debug_hex(acsi_id_mask, 2);
    debug("");
    set_acsi_ids(acsi_id_mask);
}

// Read one block from SD card for debugging
void debug_read_block(logical_drive_t *device, uint32_t addr) {
    sdcard_state_t *sdcard = device->sdcard;
    uint8_t *buffer = &sd_buffer[0][0];

    // Calculate adjusted address
    uint32_t sd_addr = addr;
    if (sdcard->type == SD_CARD_TYPE_SDSC) {
        sd_addr *= 512;
    }

    sd_select(sdcard->bus_id);
    sd_command(SD_CMD_17_BLOCK_READ, sd_addr);
    uint8_t result = sd_response_r1();

    // If a reply was received
    if (result != 0xff) {

        // Wait for card to be ready to send data. It will send 0xff while it's preparing
        result = wait_spi_response(100, 0xff);
        if (result == 0xff) {
            sd_unselect();
            green_led_off();
            debug_nocr("*** ERR SD timeout reading blk ");
            debug_hex(addr, 8);
            debug("");
            return;
        }

        if (result == SD_CMD_BLOCK_READY_TOKEN) {
            // Go!
            sdcard_read_sector_to_buffer(sd_buffer[0]);

            /*
            for (uint_fast16_t i = 0; i < 512; i++) {
                write_byte_nochecks(sd_buffer[0][i]);
            }
            */

        }
    } else {
        debug_nocr("*** ERR invalid resp from CMD17 reading blk ");
        debug_hex(addr, 8);
        debug("");
        return;
    }
    sd_unselect();
    
    //debug_nocr("Read 512 bytes from sector ");
    //debug_decimal(addr);
    //debug(":");

    for (int pos = 0; pos < 512; pos++) {
        if (pos % 16 == 0) {
            debug_hex(pos, 4);
            debug_nocr(": ");
        }
        debug_hex(buffer[pos], 2);

        if (pos % 16 == 15) {
            debug("");
        } else {
            debug_nocr(" ");
        }
    }
}

// Read one block from SD card for debugging
void debug_write_block(logical_drive_t *device, uint32_t addr) {
    sdcard_state_t *sdcard = device->sdcard;
    uint8_t *buffer = &sd_buffer[0][0];
    uint8_t result;

    // Calculate adjusted address
    uint32_t sd_addr = addr;
    if (sdcard->type == SD_CARD_TYPE_SDSC) {
        sd_addr *= 512;
    }

    sd_select(sdcard->bus_id);
    sd_command(SD_CMD_24_WRITE_BLOCK, addr);
    result = sd_response_r1();
    if (result != SD_RESPONSE_R1_CARD_READY) {
        sd_unselect();
        debug("SD card refused write block command");
        return;
    }


    // Start block token
    spi_transfer(SD_CMD_SINGLE_BLOCK_START_TOKEN);


    // Get buffer from FPGA
    //for (uint_fast16_t i = 0; i < 512; i++) {
    //  buffer[i] = read_byte_nochecks();
    //}

    // Send buffer to card
    sdcard_write_sector_from_buffer(buffer);

    // Wait for the card to send a response token
    result = wait_spi_response(100, 0xff);

    if ((result & 0x1f) != SD_CMD_BLOCK_DATA_ACCEPTED) {
        // Data not accepted?
        sd_unselect();

        debug_nocr("*** ERR SD data not accepted, reason: ");
        debug_hex(result, 2);
        debug("");

        return;
    } 

    // Wait for data to be written
    result = wait_spi_response2(250, 0xff);
    if (result != 0xff) {
        sd_unselect();

        debug_nocr("*** ERR SD card timeout writing blk ");
        debug_hex(addr, 2);
        debug("");

        return;
    }

    sd_command(SD_CMD_13_SEND_STATUS, 0);
    uint16_t r2_result = sd_response_r2();
    if ((r2_result | 0x0100) != SD_RESPONSE_R2_NO_ERROR) {
        debug_nocr("*** R2 reply failed: ");
        debug_hex(r2_result, 2);
        debug("");
        sd_unselect();
        return;
    }

    sd_unselect();
}


int main() {

    // After reset, HSI 48Mhz clock is in use
    // HSISYS clock is preset to HSI/4 = 12MHz
    // SYSCLK is preset to use HSISYS for clock source
    // HCLK derives from SYSCLK through prescaler value x1
    // PCLK derives from HCLK through prescaler value x1

    // Turn on the GPIO peripheral clocks for all GPIO ports
    RCC->IOPENR |= RCC_IOPENR_GPIOAEN | RCC_IOPENR_GPIOBEN | RCC_IOPENR_GPIOCEN | RCC_IOPENR_GPIODEN | RCC_IOPENR_GPIOFEN;

    // Enable DMA clock
    RCC->AHBENR |= RCC_AHBENR_DMA1EN;

    // Enable the peripheral clock to USART1
    RCC->APBENR2 |= RCC_APBENR2_USART1EN;

    // Enable the peripheral clock to SPI1
    RCC->APBENR2 |= RCC_APBENR2_SPI1EN;


    // Select prescaler for SYSCLK --> HCLK
    RCC->CFGR &= ~RCC_CFGR_HPRE; // value 0b0000 (default) = precaler x1
    //RCC->CFGR |= 0b1000 << RCC_CFGR_HPRE_Pos; // prescaler x2
    //RCC->CFGR |= 0b1001 << RCC_CFGR_HPRE_Pos; // prescaler x4
    //RCC->CFGR |= 0b1010 << RCC_CFGR_HPRE_Pos; // prescaler x8
    //RCC->CFGR |= 0b1011 << RCC_CFGR_HPRE_Pos; // prescaler x16
    //RCC->CFGR |= 0b1100 << RCC_CFGR_HPRE_Pos; // prescaler x64
    //RCC->CFGR |= 0b1101 << RCC_CFGR_HPRE_Pos; // prescaler x128
    //RCC->CFGR |= 0b1110 << RCC_CFGR_HPRE_Pos; // prescaler x256
    //RCC->CFGR |= 0b1111 << RCC_CFGR_HPRE_Pos; // prescaler x512

    // Select prescaler for HCLK --> PCLK
    RCC->CFGR &= ~RCC_CFGR_PPRE; // value 0b000 (default) = precaler x1
    //RCC->CFGR |= 0b100 << RCC_CFGR_PPRE_Pos; // prescaler x2
    //RCC->CFGR |= 0b101 << RCC_CFGR_PPRE_Pos; // prescaler x4
    //RCC->CFGR |= 0b110 << RCC_CFGR_PPRE_Pos; // prescaler x8
    //RCC->CFGR |= 0b111 << RCC_CFGR_PPRE_Pos; // prescaler x16

    // Select divider for HSIKER (default: 3, 16MHz)
    //RCC->CR &= ~RCC_CR_HSIKERDIV; // 0b000 (prescaler value 1) - 48MHz
    //RCC->CR |= RCC_CR_HSIKERDIV_0; // 0b001 (prescaler value 2) - 24MHz
    //RCC->CR |= RCC_CR_HSIKERDIV_1; // 0b010 (prescaler value 3) - 16MHz

    // Select clock source for USART1 (default: PCLK)
    RCC->CCIPR &= ~RCC_CCIPR_USART1SEL;
    //RCC->CCIPR |= RCC_CCIPR_USART1SEL_0; // SYSCLK
    //RCC->CCIPR |= RCC_CCIPR_USART1SEL_1; // HSIKER
    //RCC->CCIPR |= RCC_CCIPR_USART1SEL_2; // LSE

    // Reset USART1
    RCC->APBRSTR2 |= RCC_APBRSTR2_USART1RST;
    RCC->APBRSTR2 &= ~RCC_APBRSTR2_USART1RST;

    // Reset SPI
    RCC->APBRSTR2 |= RCC_APBRSTR2_SPI1RST;
    RCC->APBRSTR2 &= ~RCC_APBRSTR2_SPI1RST;

    // Reset DMA1
    RCC->AHBRSTR |= RCC_AHBRSTR_DMA1RST;
    RCC->AHBRSTR &= ~RCC_AHBRSTR_DMA1RST;

    // Setup device pins
    setup();

    // Setup USART1
    serial_init();

    // Speed up the clock
    clk_48MHz();

    // Debug during startup
    debug_level = 5;

    init_clock();

    debug("\n\r\n\r\n\r-- Startup");
    _delay_ms(50);

    // Setup SPI pins
    spi_setup();
    sdcard_setup();
    rtc_setup();

    debug("Setup done");
    // Settle down for a bit
    _delay_ms(10);

    // Flash both lights to indicate startup
    for (uint8_t i = 0; i < 2; i++) {
        red_led_on();
        green_led_on();
        _delay_ms(100);

        red_led_off();
        green_led_off();
        _delay_ms(100);
    }

    debug("Lights flashed");

    // Reset FPGA registers to default
    // This sets command mode, and ACSI bus direction IN
    extra_data_byte = EXTRA_BYTE_DEFAULT;
    write_extra_byte();

    // AVR bus pins to default
    clear_extra_data();
    clear_extra2_data();
    clear_ready();
    set_data_in();
    strobe_cs(); // Ensures CS is deasserted (afterwards)

    // Set defaults for SD cards
    sdcard_defaults(&sdcards[0], 0);
    sdcard_defaults(&sdcards[1], 1);
    
    // Default logical device info
    logical_drive[0].acsi_id = 0;
    logical_drive[0].sdcard = &sdcards[0];
    logical_drive[0].sense_key = 0;

    logical_drive[1].acsi_id = 1;
    logical_drive[1].sdcard = &sdcards[1];
    logical_drive[1].sense_key = 0;

    set_acsi_id_mask();

    // Now turn debug down until requested
    debug_level = 5;

    spi_fast();
    
    // Wait to read data
    set_data_in();

    while (1) {

        uint8_t is_cmd = 0;
        uint8_t cmd_byte = 0;

        set_data_in();
        do {
            // Wait for A_INT
            while (get_int() == 0) {

                // Check if debug level was changed by typing 0-9 on the serial port
                int16_t serial_in = serial_receive_nowait();
                if (serial_in >= 0) {
                    if (serial_in >= '0' && serial_in <= '9') {
                        debug_level = serial_in - '0';
                        serial_send("Debug level set to: ");
                        serial_sendchar('0' + debug_level);
                        serial_send("\r\n");
                    }
                }

                // Check if SD cards were removed
                if (sdcards[0].detected && !sdcard0_present()) {
                    debug("SD card 0 removed");
                    sdcard_defaults(&sdcards[0], 0);
                    logical_drive[0].media_changed = 1;
                    set_acsi_id_mask();
                }
                if (sdcards[1].detected && !sdcard1_present()) {
                    debug("SD card 1 removed");
                    sdcard_defaults(&sdcards[1], 1);
                    logical_drive[1].media_changed = 1;
                    set_acsi_id_mask();
                }

                // Check if SD cards were inserted
                if (sdcards[0].detected == 0 && sdcard0_present()) {
                    debug("SD card 0 inserted");
                    sdcards[0].detected = 1;
                    sdcard_init(&sdcards[0]);
                    logical_drive[0].media_changed = 1;
                    set_acsi_id_mask();
                }
                
                if (sdcards[1].detected == 0 && sdcard1_present()) {
                    debug("SD card 1 inserted");
                    sdcards[1].detected = 1;
                    sdcard_init(&sdcards[1]);
                    logical_drive[1].media_changed = 1;
                    set_acsi_id_mask();
                }
            }

            // Pick up byte from data bus and A_CMD pin
            is_cmd = A_CMD_PORT->IDR & _BV(A_CMD_BIT) ? 1 : 0;
            cmd_byte = read_data_port();

            strobe_cs();
        } while (!is_cmd);

        // Wait for the first byte of a command to arrive
        uint8_t acsi_device = cmd_byte >> 5;
        acsi_opcode_t opcode = cmd_byte & 0x1f;

        // Find command phase timeout length of 250ms in ticks 
        uint32_t start_time = get_clock();
        uint32_t target_time = start_time + 250;

        // Work out which device was selected from the ACSI ID of the command byte
        logical_drive_t* selected_device;
        if (acsi_device == logical_drive[0].acsi_id) {
            selected_device = &logical_drive[0];
        } else if (acsi_device == logical_drive[1].acsi_id) {
            selected_device = &logical_drive[1];
        } else {
            // Wrong device selected - should be impossible
            debug_nocr("*** ERROR: Got bad ACSI ID ");
            debug_decimal(acsi_device);
            debug_nocr(" with command ");
            debug_hex(opcode, 2);
            debug("!");

            // Manually unselect device and restart
            extra_data_byte |= 0b01000000;
            write_extra_byte();
            extra_data_byte &= 0b10111111;

            continue;
        }

        debug_nocr("ACSI ID: ");
        debug_decimal(acsi_device);
        debug_nocr(" CMD: ");
        debug_hex(opcode, 2);
        debug("");

        // We are now reading the rest of the command packet
        cmd_length = 0;

        // Don't go beyond the command buffer size
        if (cmd_length < MAX_CMD_LENGTH) {
            cmdbuf[cmd_length] = cmd_byte;
        }
        cmd_length++;

        uint8_t expected_cmd_length = 6;
        
        // Error flag will become true if the command phase times out
        uint8_t error = 0;

        while (cmd_length < expected_cmd_length) {
            cmd_byte = read_command_byte(target_time);

            if (get_clock() >= target_time) {
                debug("Timeout error in command phase");
                error = 1;
                break;
            }

            if (cmd_length < MAX_CMD_LENGTH) {
                cmdbuf[cmd_length] = cmd_byte;
                cmd_length++;
            }

            // After 1 byte, adjust the command length for ICD_ESCAPE 
            // opcode commands
            if (cmd_length == 2) {
                if (opcode == ICD_ESCAPE) {
                    if (cmd_byte < 0x20) {
                        // 6-byte command
                        expected_cmd_length = 7;
                    } else if (cmd_byte < 0x60) {
                        // 10-byte command
                        expected_cmd_length = 11;
                    } else if (cmd_byte < 0xa0) {
                        // 16-byte command
                        expected_cmd_length = 17;
                    } else {
                        // 12-byte command
                        expected_cmd_length = 13;
                    }
                }
            }
        }

        if (error == 0) {

            // Handle command, and do data transfers
            acsi_status_t status;
/*
            if (selected_device->media_changed && opcode != REQUEST_SENSE_6) {
                // If media changed, all commands response with CHECK CONDITION
                // until cleared by a REQUEST SENSE check.
                status = STATUS_CHECK_CONDITION;
            } else {
*/
                switch (opcode) {

                    // Only opcodes in the range 0 - 0x1f are possible here

                    case TEST_UNIT_READY_6:
                        status = acsi_test_unit_ready(selected_device, 0);
                        break;

                    case REQUEST_SENSE_6:
                        // First command issued by ICDTOOLS IDCHECK
                        status = acsi_request_sense(selected_device, 0);
                        break;

                    case FORMAT_UNIT_6:
                        status = acsi_format_unit(selected_device, 0);
                        break;

                    case READ_6:
                        status = acsi_read(selected_device, 0);
                        break;

                    case WRITE_6:
                        status = acsi_write(selected_device, 0);
                        break;

                    // I don't think we really need to support this
                    //case REASSIGN_BLOCKS_6:
                    //    status = acsi_reassign_blocks(selected_device, 0);
                    //    break;

                    case MODE_SELECT_6:
                        status = acsi_mode_select(selected_device, 0);
                        break;

                    case MODE_SENSE_6:
                        status = acsi_mode_sense_6(selected_device, 0);
                        break;

                    case INQUIRY_6:
                        status = scsi_inquiry(selected_device, 0);
                        break;

                    // ICD custom commands
                    case ICD_ESCAPE:
                        status = acsi_icd_escape(selected_device);
                        break;

                    default:
                        selected_device->sense_key = CMD_ERR_INVALID_COMMAND;
                        status = STATUS_CHECK_CONDITION;
                        break;
                }
//            }

            // Send status byte
            set_command_mode();
            set_data_out();
            send_status(status);
        }

        // Manually unselect device and clear buffers
        extra_data_byte |= 0b01000001;
        write_extra_byte();
        extra_data_byte &= 0b10111110;
    }

    return 0;
}

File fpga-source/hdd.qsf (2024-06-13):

# -------------------------------------------------------------------------- #
#
# Copyright (C) 2019  Intel Corporation. All rights reserved.
# Your use of Intel Corporation's design tools, logic functions 
# and other software and tools, and any partner logic 
# functions, and any output files from any of the foregoing 
# (including device programming or simulation files), and any 
# associated documentation or information are expressly subject 
# to the terms and conditions of the Intel Program License 
# Subscription Agreement, the Intel Quartus Prime License Agreement,
# the Intel FPGA IP License Agreement, or other applicable license
# agreement, including, without limitation, that your use is for
# the sole purpose of programming logic devices manufactured by
# Intel and sold by Intel or its authorized distributors.  Please
# refer to the applicable agreement for further details, at
# https://fpgasoftware.intel.com/eula.
#
# -------------------------------------------------------------------------- #
#
# Quartus Prime
# Version 19.1.0 Build 670 09/22/2019 SJ Lite Edition
# Date created = 15:24:56  June 21, 2020
#
# -------------------------------------------------------------------------- #
#
# Notes:
#
# 1) The default values for assignments are stored in the file:
#		hdd_assignment_defaults.qdf
#    If this file doesn't exist, see file:
#		assignment_defaults.qdf
#
# 2) Altera recommends that you do not modify this file. This
#    file is updated automatically by the Quartus Prime software
#    and any changes you make may be lost or overwritten.
#
# -------------------------------------------------------------------------- #


set_global_assignment -name FAMILY "MAX V"
set_global_assignment -name DEVICE 5M80ZT100I5
set_global_assignment -name TOP_LEVEL_ENTITY hdd
set_global_assignment -name ORIGINAL_QUARTUS_VERSION 19.1.0
set_global_assignment -name PROJECT_CREATION_TIME_DATE "15:24:56  JUNE 21, 2020"
set_global_assignment -name LAST_QUARTUS_VERSION "23.1std.0 Lite Edition"
set_global_assignment -name PROJECT_OUTPUT_DIRECTORY output_files
set_global_assignment -name MIN_CORE_JUNCTION_TEMP "-40"
set_global_assignment -name MAX_CORE_JUNCTION_TEMP 125
set_global_assignment -name DEVICE_FILTER_PACKAGE "ANY QFP"
set_global_assignment -name ERROR_CHECK_FREQUENCY_DIVISOR "-1"
set_global_assignment -name VERILOG_FILE hdd.v
set_location_assignment PIN_96 -to f_data[1]
set_location_assignment PIN_95 -to f_data[0]
set_location_assignment PIN_98 -to f_data[3]
set_location_assignment PIN_97 -to f_data[2]
set_location_assignment PIN_100 -to f_data[5]
set_location_assignment PIN_99 -to f_data[4]
set_location_assignment PIN_3 -to f_data[7]
set_location_assignment PIN_2 -to f_data[6]
set_location_assignment PIN_4 -to f_bus_dir
set_location_assignment PIN_75 -to f_cs
set_location_assignment PIN_78 -to f_reset
set_location_assignment PIN_77 -to f_ack
set_location_assignment PIN_76 -to f_a1
set_location_assignment PIN_74 -to f_rw
set_location_assignment PIN_73 -to f_irq
set_location_assignment PIN_72 -to f_drq
set_location_assignment PIN_28 -to a_cmd
set_location_assignment PIN_42 -to a_data[0]
set_location_assignment PIN_34 -to a_cs
set_location_assignment PIN_41 -to a_data[1]
set_location_assignment PIN_29 -to a_bus_dir
set_location_assignment PIN_40 -to a_data[2]
set_location_assignment PIN_49 -to a_int
set_location_assignment PIN_39 -to a_data[3]
set_location_assignment PIN_38 -to a_data[4]
set_location_assignment PIN_37 -to a_data[5]
set_location_assignment PIN_36 -to a_data[6]
set_location_assignment PIN_35 -to a_data[7]
set_location_assignment PIN_14 -to clock
set_global_assignment -name POWER_PRESET_COOLING_SOLUTION "NO HEAT SINK WITH STILL AIR"
set_global_assignment -name TIMING_ANALYZER_MULTICORNER_ANALYSIS OFF
set_global_assignment -name NUM_PARALLEL_PROCESSORS 2
set_global_assignment -name ENABLE_OCT_DONE OFF
set_global_assignment -name USE_CONFIGURATION_DEVICE ON
set_global_assignment -name RESERVE_ALL_UNUSED_PINS "AS INPUT TRI-STATED WITH WEAK PULL-UP"
set_location_assignment PIN_5 -to a_reset
set_location_assignment PIN_50 -to a_ready
set_location_assignment PIN_26 -to a_extra
set_location_assignment PIN_27 -to a_extra_2

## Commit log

2024-04-12 Added PCB source files
    [AtariHDisk-v1-bom.csv, AtariHDisk-v1-bom.ods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]
2024-04-13 Added fus config to Makefile to fix reset pin Fixed RXC interrupt enable flag in serial code Allow debug level to be changed any time
    [commands.c, fpga_comm.h, main.c]
2024-04-23 Fixed a few issues with SD card timeouts Made SD cards detect changes
    [commands.c, fpga_comm.h, main.c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]
2024-04-23 Removed device programmer config file and added it to .gitignore
2024-04-27 Fixed bug in capacity check
    [commands.c, rtc.c]
2024-04-29 Experimental: interrupt-driven double-buffered SPI comms for SD card
2024-05-01 Fix off-by-one in READ CAPACITY (10)
    [commands.c]
2024-05-01 Fixed 2 typos; deleted the debug LED functions from fpga_comm.h
    [fpga_comm.h]
2024-06-13 STM32C01 version, now in a working state (#6)
    Code for V2 board, proven and now working.
    [AtariHDisk-v2-bom.ods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]
